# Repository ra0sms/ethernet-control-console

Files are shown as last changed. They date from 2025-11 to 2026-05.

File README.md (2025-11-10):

### Ethernet control console

The device allows you to control 8 outputs via an Ethernet connection. The main outputs control voltage and are also duplicated by open-collector outputs.

Input VDC: 5-45 V

Output current: 500 mA for all 8 outputs (also 500 mA for all open-collector outputs)

PCB dimension: 78*88 mm

[WI-FI version with the same functionality](https://github.com/ra0sms/ESP8266_antenna_switch)

More information - https://ra0sms.com/ethernet-control-console

#### Schematic

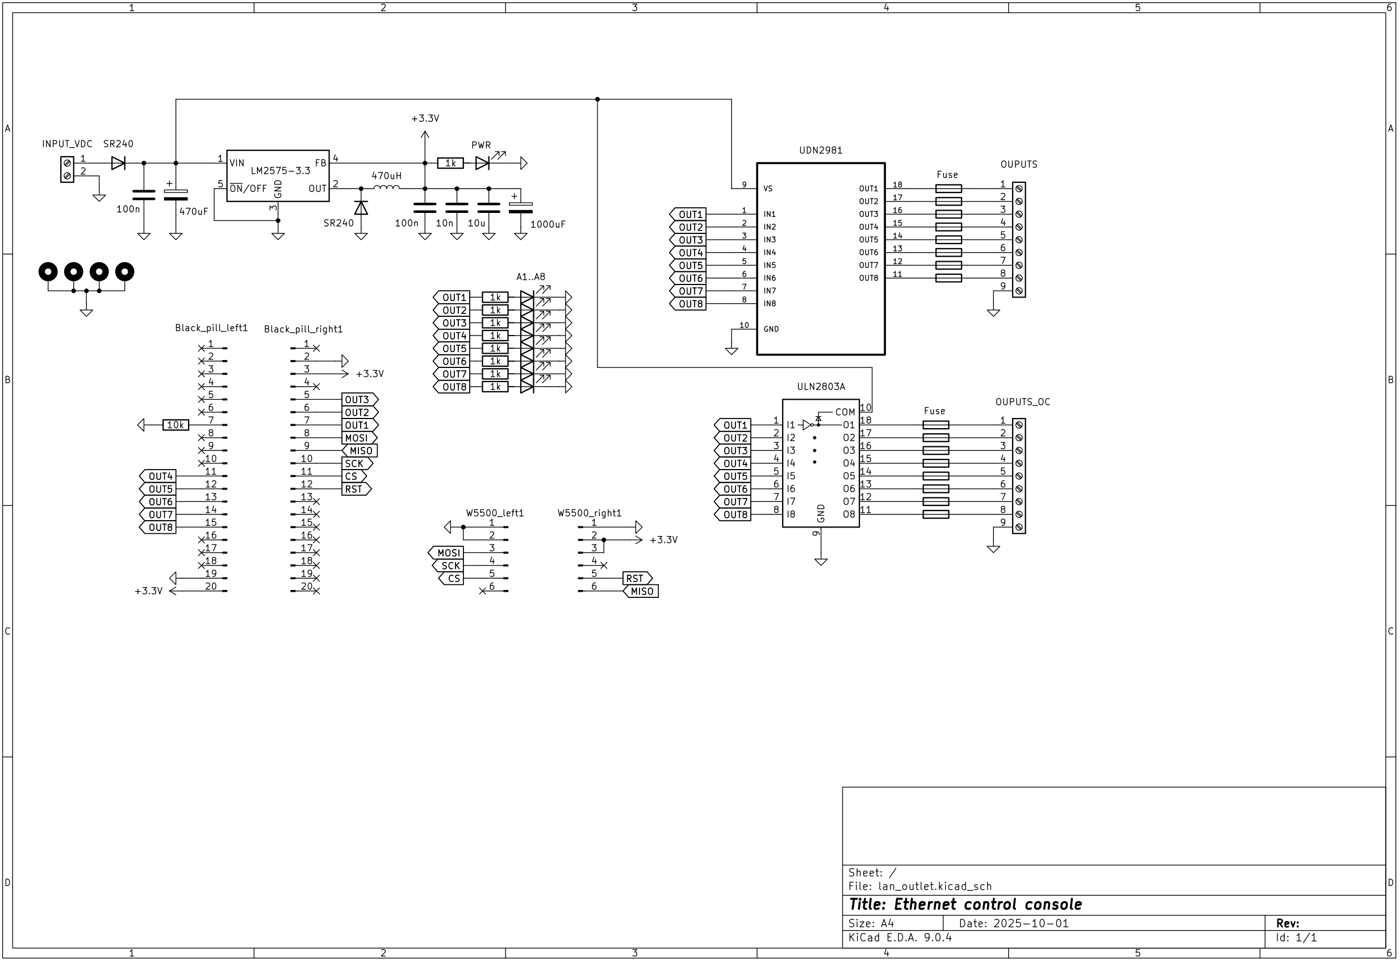
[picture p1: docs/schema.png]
schema


#### PCB

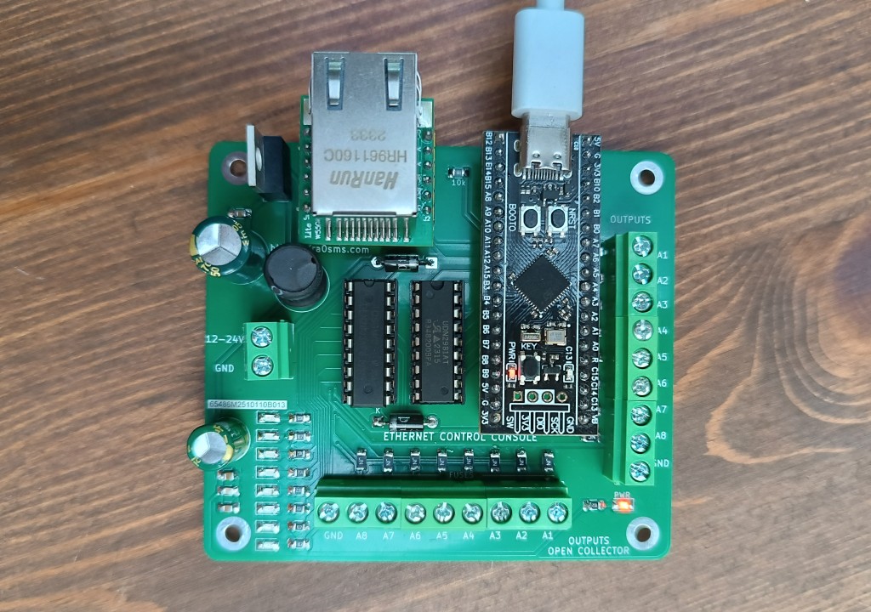
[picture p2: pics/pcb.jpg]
pcb


#### Boxed version

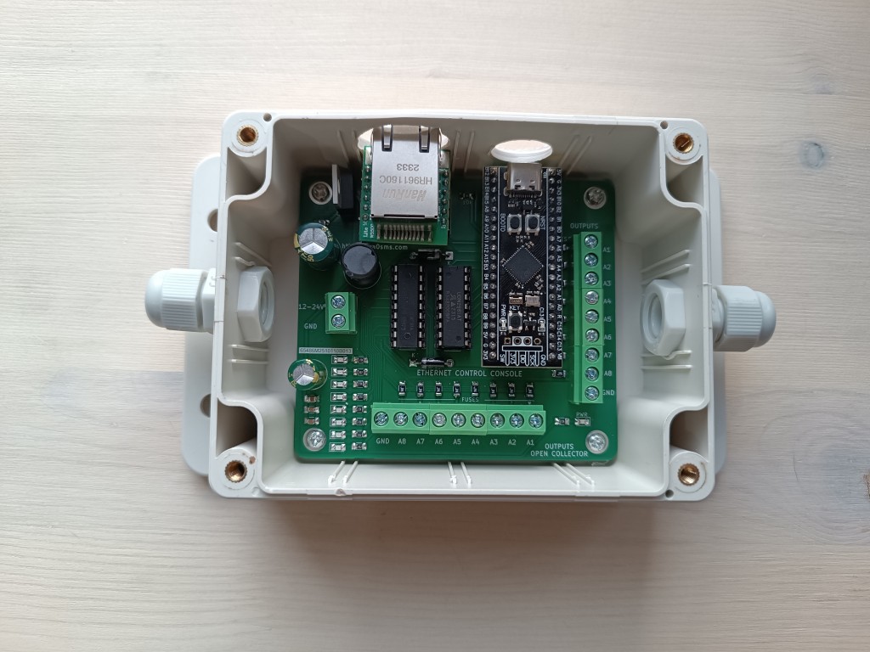
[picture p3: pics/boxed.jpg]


#### Web interface

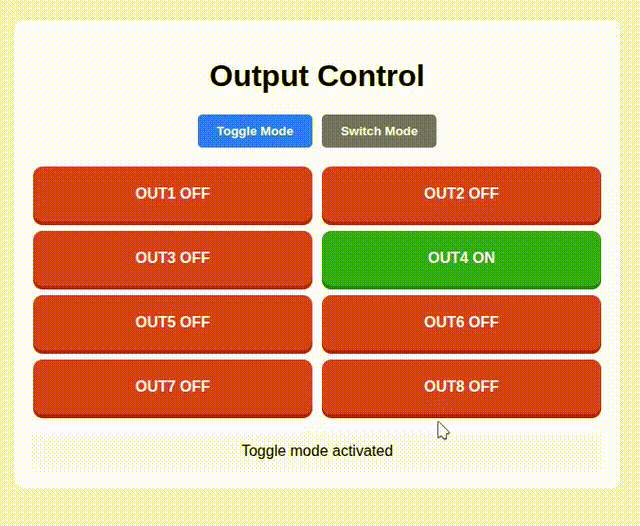
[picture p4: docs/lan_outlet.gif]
web


#### Configuration software

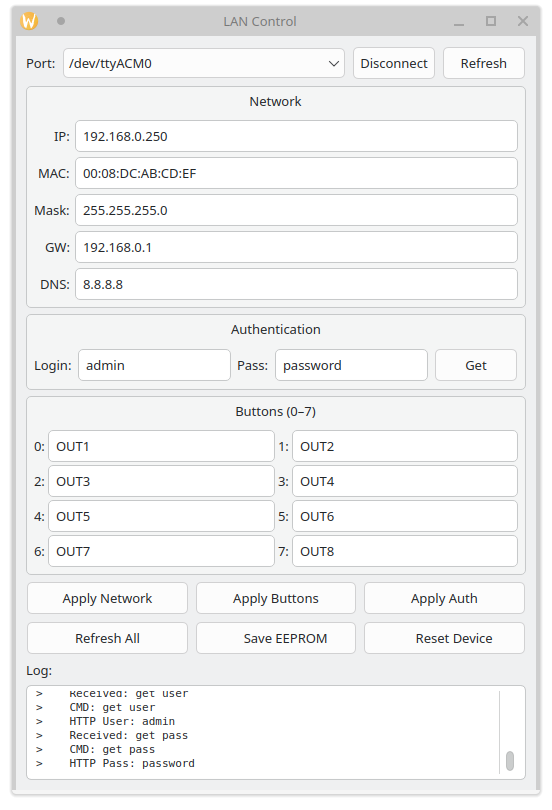
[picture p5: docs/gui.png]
gui


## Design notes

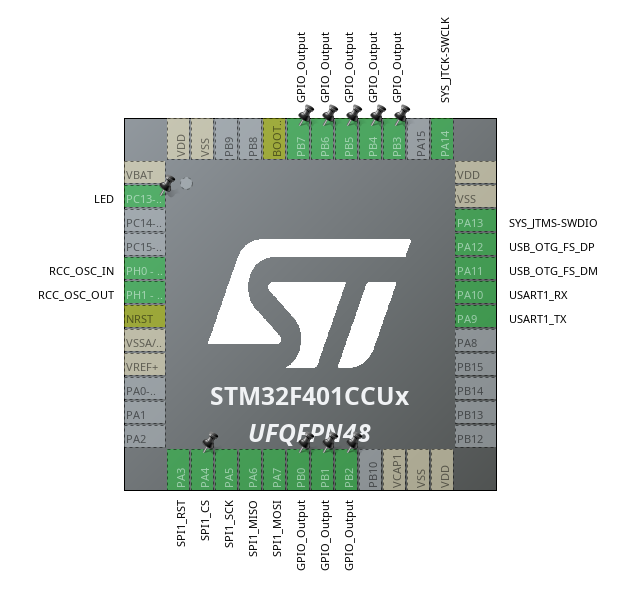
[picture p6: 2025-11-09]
docs/lan_outlet_pinout.png

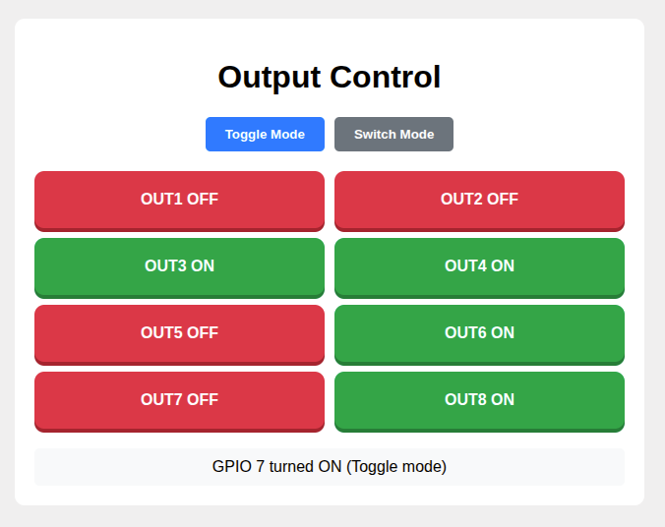
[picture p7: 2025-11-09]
docs/web.png

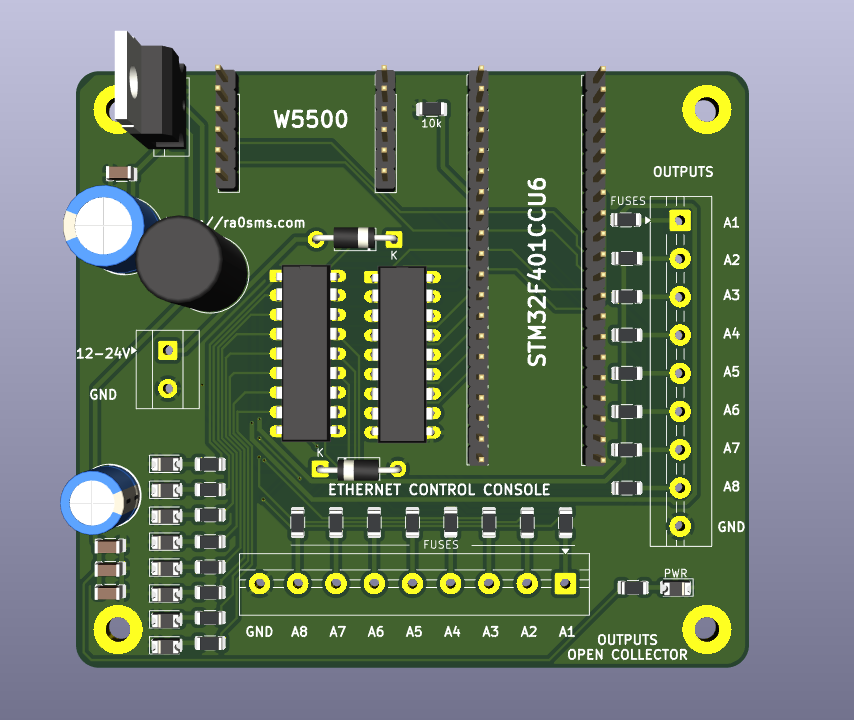
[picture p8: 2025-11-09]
docs/3d.png

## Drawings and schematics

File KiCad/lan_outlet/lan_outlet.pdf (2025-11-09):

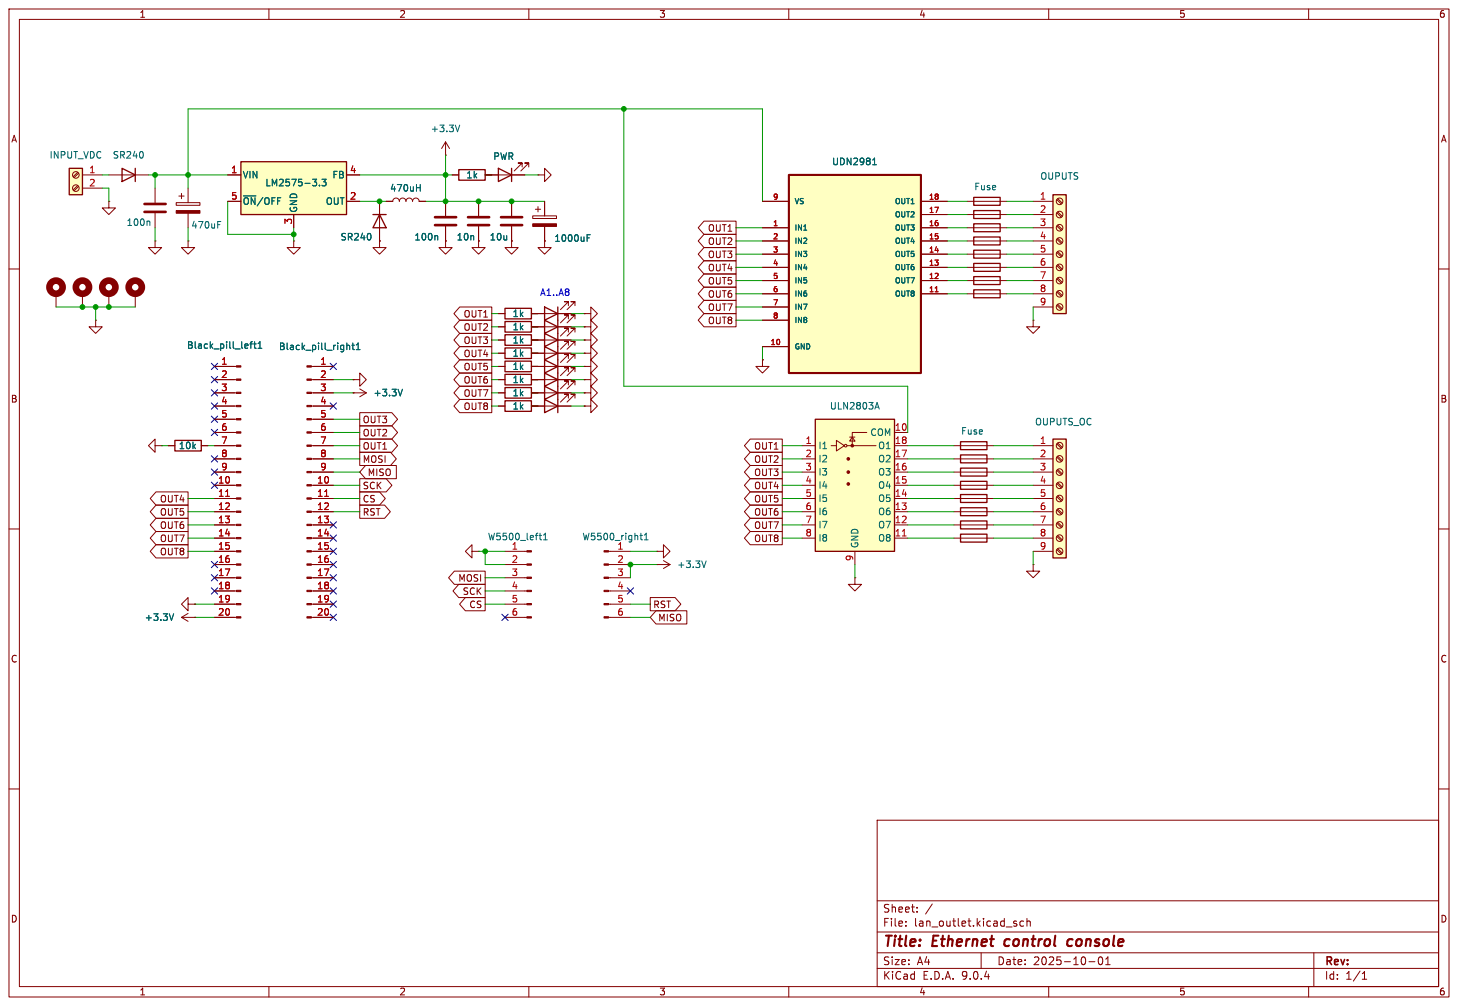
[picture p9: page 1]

File: lan_outlet.kicad_sch Sheet: /
Id: 1/1 Title: Ethernet control console

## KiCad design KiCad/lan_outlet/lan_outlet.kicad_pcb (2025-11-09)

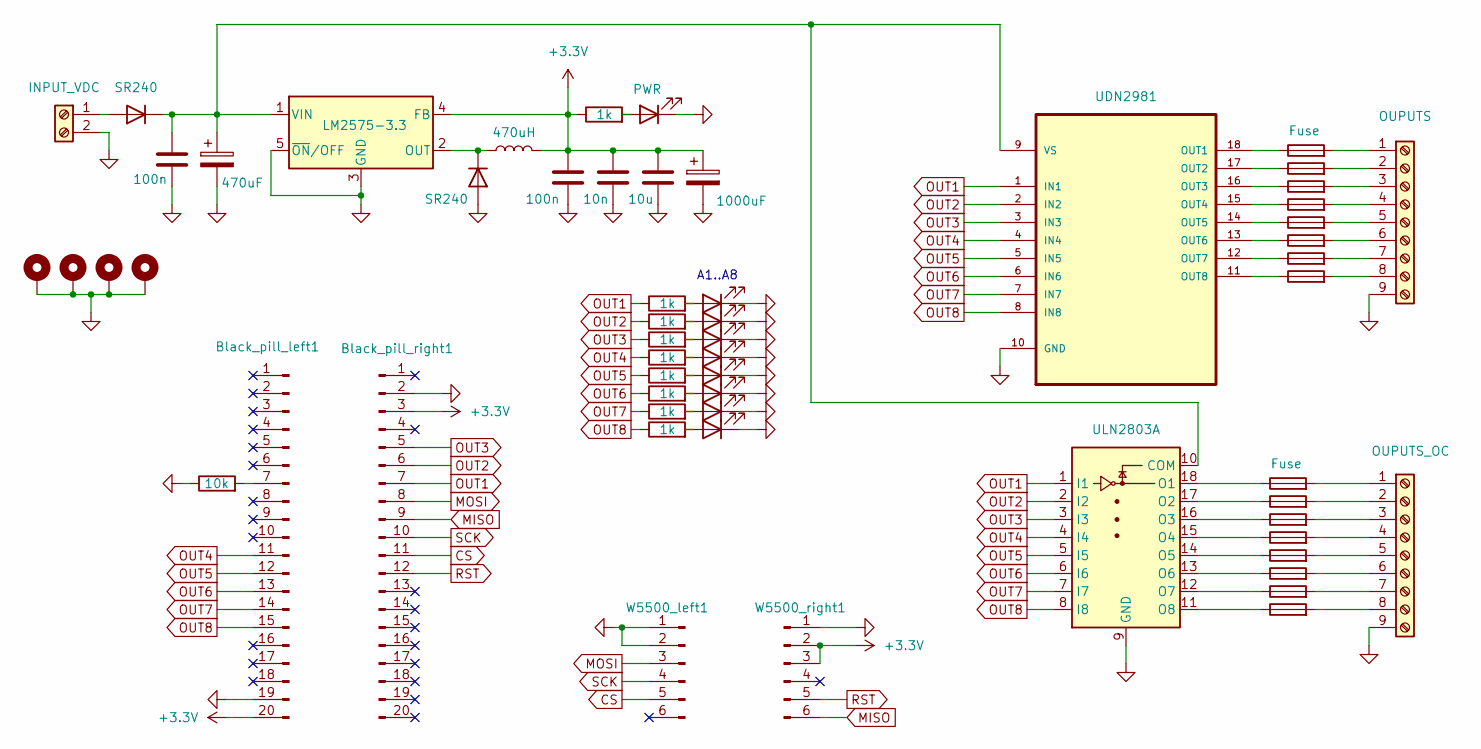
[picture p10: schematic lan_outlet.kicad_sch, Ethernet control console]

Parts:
Black_pill_left1: Conn_01x20_Pin; PinHeader_1x20_P2.54mm_Vertical
Black_pill_right1: Conn_01x20_Pin; PinHeader_1x20_P2.54mm_Vertical
C1, C3: 100n; C_1206_3216Metric
C2: 470uF; CP_Radial_D10.0mm_P5.00mm
C4: 10n; C_1206_3216Metric
C5: 10u; C_1206_3216Metric
C6: 1000uF; CP_Radial_D8.0mm_P3.80mm
D1, D2: SR240; D_DO-41_SOD81_P10.16mm_Horizontal
D3: PWR; D_1206_3216Metric
D4, D5, D6, D7, D8, D9, D10, D11: A1; D_1206_3216Metric
F1, F2, F3, F4, F5, F6, F7, F8, F9, F10, F11, F12, F13, F14, F15, F16: Fuse; R_1206_3216Metric
H1, H2, H3, H4: MountingHole_Pad; MountingHole_3.2mm_M3_Pad
J1: INPUT_VDC; TerminalBlock_MetzConnect_Type055_RT01502HDWU_1x02_P5.00mm_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
J2: OUPUTS; TerminalBlock_MaiXu_MX126-5.0-09P_1x09_P5.00mm
J3: OUPUTS_OC; TerminalBlock_MaiXu_MX126-5.0-09P_1x09_P5.00mm
L1: 470uH; L_Radial_D10.0mm_P5.00mm_Neosid_SD12_style3
R1: 10k; R_1206_3216Metric
R2, R3, R4, R5, R6, R7, R8, R9, R10: 1k; R_1206_3216Metric
U1: LM2575-3.3; TO-220-5_Vertical
U2: UDN2981; DIP-18_W7.62mm_LongPads; MPN UDN2981
U3: ULN2803A; DIP-18_W7.62mm_LongPads
W5500_left1, W5500_right1: Conn_01x06_Pin; PinHeader_1x06_P2.54mm_Vertical

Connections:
+3.3V: Black_pill_left1.20, Black_pill_right1.3, C3.1, C4.1, C5.1, C6.1, L1.2, R2.1, U1.4 (FB), W5500_right1.2, W5500_right1.3
CS: Black_pill_right1.11, W5500_left1.5
GND: Black_pill_left1.19, Black_pill_right1.2, C1.2, C2.2, C3.2, C4.2, C5.2, C6.2, D2.2 (A), D3.1 (K), D4.1 (K), D5.1 (K), D6.1 (K), D7.1 (K), D8.1 (K), D9.1 (K), D10.1 (K), D11.1 (K), H1.1, H2.1, H3.1, H4.1, J1.2, J2.9, J3.9, R1.1, U1.3 (GND), U1.5 (~ON/OFF), U2.10 (GND), U3.9 (GND), W5500_left1.1, W5500_left1.2, W5500_right1.1
MISO: Black_pill_right1.9, W5500_right1.6
MOSI: Black_pill_right1.8, W5500_left1.3
unnamed: Black_pill_left1.7, R1.2
unnamed: D1.2 (A), J1.1
unnamed: C1.1, C2.1, D1.1 (K), U1.1 (VIN), U2.9 (VS), U3.10 (COM)
unnamed: D2.1 (K), L1.1, U1.2 (OUT)
unnamed: D3.2 (A), R2.2
unnamed: D4.2 (A), R3.2
unnamed: D5.2 (A), R4.2
unnamed: D6.2 (A), R5.2
unnamed: D7.2 (A), R6.2
unnamed: D8.2 (A), R7.2
unnamed: D9.2 (A), R8.2
unnamed: D10.2 (A), R9.2
unnamed: D11.2 (A), R10.2
unnamed: F9.2, J2.1
unnamed: F10.2, J2.2
unnamed: F11.2, J2.3
unnamed: F12.2, J2.4
unnamed: F13.2, J2.5
unnamed: F14.2, J2.6
unnamed: F15.2, J2.7
unnamed: F16.2, J2.8
unnamed: F1.2, J3.1
unnamed: F2.2, J3.2
unnamed: F3.2, J3.3
unnamed: F4.2, J3.4
unnamed: F5.2, J3.5
unnamed: F6.2, J3.6
unnamed: F7.2, J3.7
unnamed: F8.2, J3.8
unnamed: F9.1, U2.18 (OUT1)
unnamed: F10.1, U2.17 (OUT2)
unnamed: F11.1, U2.16 (OUT3)
unnamed: F12.1, U2.15 (OUT4)
unnamed: F13.1, U2.14 (OUT5)
unnamed: F14.1, U2.13 (OUT6)
unnamed: F15.1, U2.12 (OUT7)
unnamed: F16.1, U2.11 (OUT8)
unnamed: F1.1, U3.18 (O1)
unnamed: F2.1, U3.17 (O2)
unnamed: F3.1, U3.16 (O3)
unnamed: F4.1, U3.15 (O4)
unnamed: F5.1, U3.14 (O5)
unnamed: F6.1, U3.13 (O6)
unnamed: F7.1, U3.12 (O7)
unnamed: F8.1, U3.11 (O8)
OUT1: Black_pill_right1.7, R3.1, U2.1 (IN1), U3.1 (I1)
OUT2: Black_pill_right1.6, R4.1, U2.2 (IN2), U3.2 (I2)
OUT3: Black_pill_right1.5, R5.1, U2.3 (IN3), U3.3 (I3)
OUT4: Black_pill_left1.11, R6.1, U2.4 (IN4), U3.4 (I4)
OUT5: Black_pill_left1.12, R7.1, U2.5 (IN5), U3.5 (I5)
OUT6: Black_pill_left1.13, R8.1, U2.6 (IN6), U3.6 (I6)
OUT7: Black_pill_left1.14, R9.1, U2.7 (IN7), U3.7 (I7)
OUT8: Black_pill_left1.15, R10.1, U2.8 (IN8), U3.8 (I8)
RST: Black_pill_right1.12, W5500_right1.5
SCK: Black_pill_right1.10, W5500_left1.4

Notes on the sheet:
A1..A8

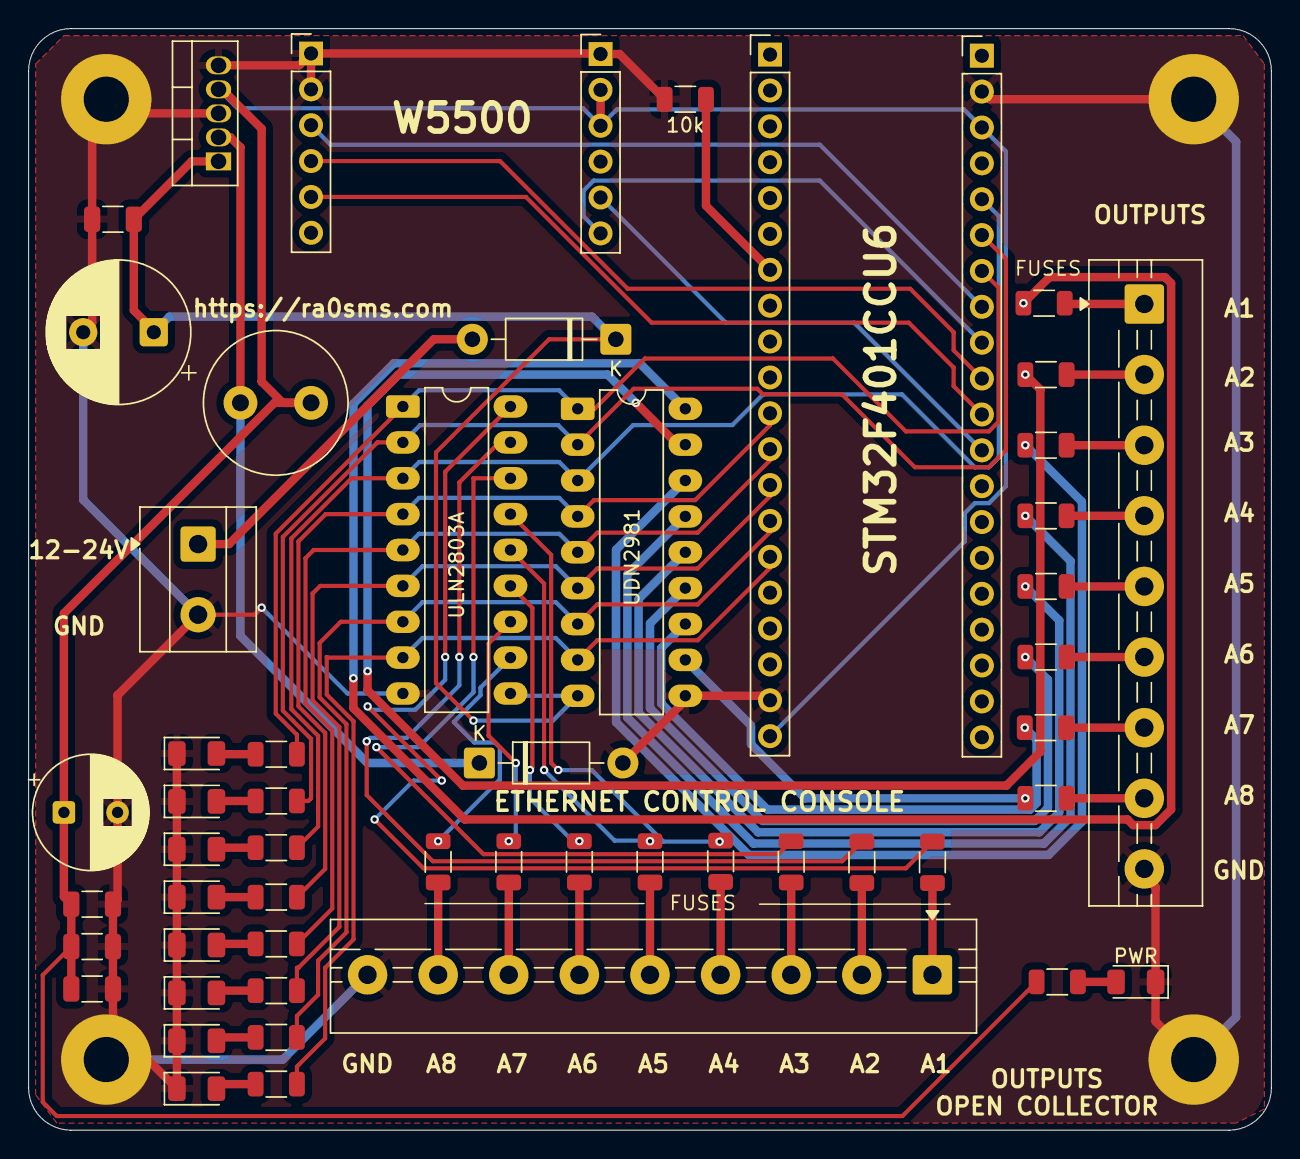
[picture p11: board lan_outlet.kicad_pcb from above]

Board: 2 copper layers, 88.0 x 78.0 mm, 58 parts (0 on the bottom side), 60 nets.

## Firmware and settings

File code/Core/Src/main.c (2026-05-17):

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
/* Includes ------------------------------------------------------------------*/
#include "main.h"
#include "usb_device.h"
#include "usbd_cdc_if.h"

/* USER CODE BEGIN Includes */
#include "socket.h"
#include <stdio.h>
#include <string.h>
#include <ctype.h>
#include "stm32f4xx_hal_flash.h"

#define AUTH_ON
#define HTTP_SOCKET     0
#define DATA_BUF_SIZE   16384
#define MAX_SOCK_NUM 8
#define HTTP_PORT 80
#define EEPROM_START_ADDRESS 0x08030000
#define EEPROM_MAGIC_NUMBER 0xABCD1235

uint8_t gDATABUF[DATA_BUF_SIZE];
uint8_t stat;
uint32_t socket_active_since = 0;
char g_http_user[32] = "admin";
char g_http_pass[32] = "password";
char g_http_base64[64] = "";

extern volatile uint8_t usb_rx_buffer[USB_RX_BUFFER_SIZE];
extern volatile uint16_t usb_rx_index;
extern volatile uint8_t usb_rx_ready;
extern volatile uint8_t usb_rx_error;


uint8_t gpio_states[8] = {0};
char last_status_message[128] = {0};
uint8_t operation_mode = 0;
uint8_t dual_mode_group1 = 0;
uint8_t dual_mode_group2 = 0;
char mode_names[3][16] = {"Toggle Mode", "Switch Mode", "Dual Mode"};

int ParseIPAddress(const char* ip_str, uint8_t* ip_array);
int ParseMACAddress(const char* mac_str, uint8_t* mac_array);
void ApplyNetworkSettings(void);
void ShowNetworkInfo(void);
void ProcessSetCommand(char* args);
void ProcessGetCommand(char* args);
void ProcessSetButtonCommand(char* args);
void LoadButtonNamesFromEEPROM(void);
void ShowButtonNames(void);
void TrimWhitespace(char* str);

#pragma pack(push, 1)
typedef struct {
    uint32_t magic;
    wiz_NetInfo netinfo;
    char button_names[8][16];
    char http_user[32];
    char http_pass[32];
    uint32_t crc;
} EEPROM_Data;
#pragma pack(pop)

char button_names[8][16] = {
    "OUT1", "OUT2", "OUT3", "OUT4",
    "OUT5", "OUT6", "OUT7", "OUT8"
};


const char *http_headers =
    "HTTP/1.1 200 OK\r\n"
    "Content-Type: text/html\r\n"
    "Connection: close\r\n"
    "\r\n";


const char *main_page =
    "<!DOCTYPE html>"
    "<html><head><title>LAN Control Console</title>"
    "<meta charset='UTF-8'>"
    "<meta name='viewport' content='width=device-width, initial-scale=1.0'>"
    "<style>"
    "body{font-family:Arial;background:#f0f0f0;text-align:center;padding:20px;}"
    ".container{background:white;border-radius:10px;padding:20px;margin:0 auto;max-width:600px;}"
    ".mode-selector{margin:15px 0;}"
    ".mode-btn{padding:10px 20px;margin:0 5px;border:none;border-radius:5px;cursor:pointer;font-weight:bold;}"
    ".mode-active{background:#007bff;color:white;}"
    ".mode-inactive{background:#6c757d;color:white;}"
    ".btn-grid{display:grid;grid-template-columns:repeat(2,1fr);gap:10px;margin:20px 0;}"
    ".btn{display:block;padding:20px;border-radius:10px;text-decoration:none;font-size:16px;font-weight:bold;transition:all 0.3s;}"
    ".btn-on{background:#28a745;color:white;box-shadow:0 4px #1e7e34;}"
    ".btn-off{background:#dc3545;color:white;box-shadow:0 4px #a71e2a;}"
    ".btn:hover{opacity:0.9;transform:translateY(-2px);}"
    ".status{margin-top:20px;padding:10px;border-radius:5px;background:#f8f9fa;}"
    "</style>"
    "</head>"
    "<body>"
    "<div class='container'>"
    "<h1>Output Control</h1>";


/* USER CODE END Includes */

SPI_HandleTypeDef hspi1;

UART_HandleTypeDef huart1;

/* USER CODE BEGIN PV */
wiz_NetInfo gWIZNETINFO = { .mac = {0x00, 0x08, 0xdc, 0xab, 0xcd, 0xef},
                            .ip = {192, 168, 0, 250},
                            .sn = {255, 255, 255, 0},
                            .gw = {192, 168, 0, 1},
                            .dns = {0, 0, 0, 0},
                            .dhcp = NETINFO_STATIC };



static const char base64_chars[] = "ABCDEFGHIJKLMNOPQRSTUVWXYZabcdefghijklmnopqrstuvwxyz0123456789+/";

void base64_encode(const unsigned char* data, size_t input_length, char* output) {
    size_t i = 0, j = 0;
    uint32_t triple;

    while (i + 3 <= input_length) {
        triple = (data[i] << 16) + (data[i+1] << 8) + data[i+2];
        output[j++] = base64_chars[(triple >> 18) & 0x3F];
        output[j++] = base64_chars[(triple >> 12) & 0x3F];
        output[j++] = base64_chars[(triple >>  6) & 0x3F];
        output[j++] = base64_chars[(triple      ) & 0x3F];
        i += 3;
    }

    if (i + 2 == input_length) {
        triple = (data[i] << 16) + (data[i+1] << 8);
        output[j++] = base64_chars[(triple >> 18) & 0x3F];
        output[j++] = base64_chars[(triple >> 12) & 0x3F];
        output[j++] = base64_chars[(triple >>  6) & 0x3F];
        output[j++] = '=';
    } else if (i + 1 == input_length) {
        triple = (data[i] << 16);
        output[j++] = base64_chars[(triple >> 18) & 0x3F];
        output[j++] = base64_chars[(triple >> 12) & 0x3F];
        output[j++] = '=';
        output[j++] = '=';
    }
    output[j] = '\0';
}

void UpdateHTTPBase64(void) {
    char userpass[64];
    int len = snprintf(userpass, sizeof(userpass), "%s:%s", g_http_user, g_http_pass);
    if (len > 0 && len < (int)sizeof(userpass)) {
        base64_encode((const unsigned char*)userpass, len, g_http_base64);
    } else {
        strcpy(g_http_base64, "");
    }
}


int check_authentication(uint8_t* http_request) {
    char* auth_header = strstr((char*)http_request, "Authorization: Basic ");
    if (auth_header == NULL) {
        return 0;
    }
    auth_header += strlen("Authorization: Basic ");
    char* end_of_auth = strchr(auth_header, '\r');
    if (end_of_auth == NULL) {
        return 0;
    }
    int encoded_len = end_of_auth - auth_header;
    char encoded[64] = {0};
    if (encoded_len >= 63) return 0; // safety
    strncpy(encoded, auth_header, encoded_len);
    encoded[encoded_len] = '\0';

    return (strcmp(encoded, g_http_base64) == 0);
}

void send_auth_required(uint8_t socket) {
    const char* auth_page =
        "HTTP/1.1 401 Unauthorized\r\n"
        "WWW-Authenticate: Basic realm=\"LAN Control Console\"\r\n"
        "Content-Type: text/html\r\n"
  //      "Connection: close\r\n"
        "Content-Length: 0\r\n\r\n";

    send(socket, (uint8_t*)auth_page, strlen(auth_page));
}


int _write(int file, char *ptr, int len)
{
    CDC_Transmit_FS((uint8_t*)ptr, len);
    return len;
}


void W5500_Select(void)
{
    HAL_GPIO_WritePin(SPI1_CS_GPIO_Port, SPI1_CS_Pin, GPIO_PIN_RESET);
}

void W5500_Unselect(void)
{
    HAL_GPIO_WritePin(SPI1_CS_GPIO_Port, SPI1_CS_Pin, GPIO_PIN_SET);
}

void W5500_ReadBuff(uint8_t* buff, uint16_t len)
{
    HAL_SPI_Receive(&hspi1, buff, len, 100);
}

void W5500_WriteBuff(uint8_t* buff, uint16_t len)
{
    HAL_SPI_Transmit(&hspi1, buff, len, 100);
}

uint8_t W5500_ReadByte(void)
{
    uint8_t byte;
    W5500_ReadBuff(&byte, sizeof(byte));
    return byte;
}

void W5500_WriteByte(uint8_t byte)
{
    W5500_WriteBuff(&byte, sizeof(byte));
}




uint32_t CalculateXORChecksum(const uint8_t* data, size_t length)
{
    uint32_t checksum = 0;
    for(size_t i = 0; i < length; i++) {
        checksum ^= data[i];
    }
    return checksum;
}


void WriteSettingsToEEPROM(void)
{
    EEPROM_Data eeprom_data = {0};
    eeprom_data.magic = EEPROM_MAGIC_NUMBER;
    memcpy(&eeprom_data.netinfo, &gWIZNETINFO, sizeof(wiz_NetInfo));
    for(int i = 0; i < 8; i++) {
        strncpy(eeprom_data.button_names[i], button_names[i], 15);
        eeprom_data.button_names[i][15] = '\0';
    }
    strncpy(eeprom_data.http_user, g_http_user, 31);
    eeprom_data.http_user[31] = '\0';
    strncpy(eeprom_data.http_pass, g_http_pass, 31);
    eeprom_data.http_pass[31] = '\0';
    size_t checksum_size = sizeof(EEPROM_Data) - sizeof(uint32_t);
    eeprom_data.crc = CalculateXORChecksum((uint8_t*)&eeprom_data, checksum_size);

    printf("XOR Checksum: 0x%08lX\r\n", (unsigned long)eeprom_data.crc);

    HAL_FLASH_Unlock();
    __HAL_FLASH_CLEAR_FLAG(FLASH_FLAG_EOP | FLASH_FLAG_OPERR | FLASH_FLAG_WRPERR |
                          FLASH_FLAG_PGAERR | FLASH_FLAG_PGSERR);

    FLASH_EraseInitTypeDef erase_init = {0};
    erase_init.TypeErase = FLASH_TYPEERASE_SECTORS;
    erase_init.Sector = FLASH_SECTOR_5;
    erase_init.NbSectors = 1;
    erase_init.VoltageRange = FLASH_VOLTAGE_RANGE_3;

    uint32_t sector_error = 0;
    if (HAL_FLASHEx_Erase(&erase_init, &sector_error) != HAL_OK) {
        printf("Flash erase failed\r\n");
        HAL_FLASH_Lock();
        return;
    }
    uint32_t* data_ptr = (uint32_t*)&eeprom_data;
    uint32_t word_count = (sizeof(EEPROM_Data) + 3) / 4;
    uint32_t address = EEPROM_START_ADDRESS;
    for (uint32_t i = 0; i < word_count; i++) {
        if (HAL_FLASH_Program(FLASH_TYPEPROGRAM_WORD, address + i * 4, data_ptr[i]) != HAL_OK) {
            printf("Flash write failed at word %lu\r\n", i);
            break;
        }
    }
    HAL_FLASH_Lock();
    printf("Settings saved to EEPROM\r\n");
}


uint8_t ReadSettingsFromEEPROM(void)
{
    EEPROM_Data* eeprom_data = (EEPROM_Data*)EEPROM_START_ADDRESS;

    printf("Magic in EEPROM: 0x%08X, expected: 0x%08X\r\n",
           (unsigned int)eeprom_data->magic, (unsigned int)EEPROM_MAGIC_NUMBER);

    if(eeprom_data->magic != EEPROM_MAGIC_NUMBER) {
        printf("No valid settings in EEPROM\r\n");
        return 0;
    }

    size_t checksum_size = sizeof(EEPROM_Data) - sizeof(uint32_t);
    uint32_t calculated_checksum = CalculateXORChecksum((uint8_t*)eeprom_data, checksum_size);
    printf("Stored XOR: 0x%08X, Calculated XOR: 0x%08X\r\n",
           (unsigned int)eeprom_data->crc, (unsigned int)calculated_checksum);

    if(eeprom_data->crc != calculated_checksum) {
        printf("EEPROM data corrupted (XOR checksum error)\r\n");
        return 0;
    }

    memcpy(&gWIZNETINFO, &eeprom_data->netinfo, sizeof(wiz_NetInfo));

    for(int i = 0; i < 8; i++) {
        strncpy(button_names[i], eeprom_data->button_names[i], 15);
        button_names[i][15] = '\0';
        printf("Button %d: '%s'\r\n", i, button_names[i]);
        HAL_Delay(1);
    }
    strncpy(g_http_user, eeprom_data->http_user, 31);
    g_http_user[31] = '\0';
    strncpy(g_http_pass, eeprom_data->http_pass, 31);
    g_http_pass[31] = '\0';
    UpdateHTTPBase64();
    printf("Settings loaded from EEPROM\r\n");
    return 1;
}



void LoadDefaultSettings(void)
{
    uint8_t default_mac[] = {0x00, 0x08, 0xDC, 0xAB, 0xCD, 0xEF};
    uint8_t default_ip[] = {192, 168, 0, 250};
    uint8_t default_sn[] = {255, 255, 255, 0};
    uint8_t default_gw[] = {192, 168, 0, 1};
    uint8_t default_dns[] = {8, 8, 8, 8};

    memcpy(gWIZNETINFO.mac, default_mac, 6);
    memcpy(gWIZNETINFO.ip, default_ip, 4);
    memcpy(gWIZNETINFO.sn, default_sn, 4);
    memcpy(gWIZNETINFO.gw, default_gw, 4);
    memcpy(gWIZNETINFO.dns, default_dns, 4);
    gWIZNETINFO.dhcp = NETINFO_STATIC;
    char default_names[8][16] = {
        "OUT1", "OUT2", "OUT3", "OUT4",
        "OUT5", "OUT6", "OUT7", "OUT8"
    };

    for(int i = 0; i < 8; i++) {
        strncpy(button_names[i], default_names[i], 15);
        button_names[i][15] = '\0';
    }
    strncpy(g_http_user, "admin", 31);
    g_http_user[31] = '\0';
    strncpy(g_http_pass, "password", 31);
    g_http_pass[31] = '\0';
    UpdateHTTPBase64();

    printf("Loaded default settings\r\n");
}
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
int main(void)
{
  /* MCU Configuration--------------------------------------------------------*/

  HAL_Init();
  SystemClock_Config();
  MX_GPIO_Init();
  MX_SPI1_Init();
  MX_TIM11_Init();
  MX_USB_DEVICE_Init();

  /* USER CODE BEGIN 2 */
  LL_TIM_EnableCounter(TIM11);
  LL_TIM_EnableIT_UPDATE(TIM11);

  HAL_Delay(2000);

  // Загрузка настроек из EEPROM или дефолтных
  if (!ReadSettingsFromEEPROM()) {
      LoadDefaultSettings();
      printf("Using default settings\r\n");
  } else {
      printf("Settings loaded from EEPROM\r\n");
  }
  ApplyNetworkSettings();
  UpdateHTTPBase64();

  // Инициализация режимов работы
  operation_mode = 0;              // 0=Toggle(global), 1=Switch(global), 2=Dual
  dual_mode_group1 = 0;            // 0=toggle, 1=switch для GPIO 0-3 (выходы 1-4)
  dual_mode_group2 = 0;            // 0=toggle, 1=switch для GPIO 4-7 (выходы 5-8)

  printf("System initialized\r\n");

  // Сброс и инициализация W5500
  HAL_GPIO_WritePin(SPI1_RST_GPIO_Port, SPI1_RST_Pin, GPIO_PIN_RESET);
  HAL_Delay(10);
  HAL_GPIO_WritePin(SPI1_RST_GPIO_Port, SPI1_RST_Pin, GPIO_PIN_SET);
  HAL_Delay(2000);

  reg_wizchip_cs_cbfunc(W5500_Select, W5500_Unselect);
  reg_wizchip_spi_cbfunc(W5500_ReadByte, W5500_WriteByte);
  reg_wizchip_spiburst_cbfunc(W5500_ReadBuff, W5500_WriteBuff);

  uint8_t rx_tx_buff_sizes[] = { 8, 1, 1, 1, 1, 1, 1, 1 };
  wizchip_init(rx_tx_buff_sizes, rx_tx_buff_sizes);
  wizchip_setnetinfo(&gWIZNETINFO);

  printf("W5500 initialized, IP: %d.%d.%d.%d\r\n", gWIZNETINFO.ip[0],
          gWIZNETINFO.ip[1], gWIZNETINFO.ip[2], gWIZNETINFO.ip[3]);

  if (socket(HTTP_SOCKET, Sn_MR_TCP, 80, 0) != HTTP_SOCKET) {
      printf("Socket creation failed!\r\n");
      while (1) { HAL_Delay(1000); }
  }

  if (listen(HTTP_SOCKET) != SOCK_OK) {
      printf("Listen failed!\r\n");
      while (1) { HAL_Delay(1000); }
  }

  printf("HTTP Server listening on port 80...\r\n");

  /* USER CODE END 2 */

  /* Infinite loop */
  /* USER CODE BEGIN WHILE */
  while (1)
  {
    ProcessUSBData();
    CheckW5500();
    EnsureSocketClosedIfNeeded();

    uint8_t status = getSn_SR(HTTP_SOCKET);
    uint32_t now = HAL_GetTick();

    // Контроль "зависшего" сокета
    if ((status == SOCK_ESTABLISHED || status == SOCK_CLOSE_WAIT) && socket_active_since != 0) {
        if (now - socket_active_since > 10000) {
            printf("Socket stuck >10s, force closing socket %d\r\n", HTTP_SOCKET);
            close(HTTP_SOCKET);
            socket_active_since = 0;
        }
    }

    switch (status) {
    case SOCK_ESTABLISHED: {
        if (socket_active_since == 0) {
            socket_active_since = now;
        }

        uint8_t http_request[1024] = { 0 };
        uint16_t total_len = 0;
        uint32_t recv_start = HAL_GetTick();

        // Приём HTTP-запроса
        while (total_len < sizeof(http_request) - 1) {
            int16_t len = recv(HTTP_SOCKET, http_request + total_len,
                    sizeof(http_request) - total_len - 1);

            if (len > 0) {
                total_len += len;
                recv_start = HAL_GetTick();
                if (total_len >= 4 && memcmp(http_request + total_len - 4, "\r\n\r\n", 4) == 0) {
                    break;
                }
            } else if (len == 0) {
                if (HAL_GetTick() - recv_start > 3000) {
                    printf("Recv timeout\r\n");
                    break;
                }
                HAL_Delay(1);
            } else {
                printf("Recv error: %d\r\n", len);
                break;
            }
        }

        if (total_len > 0) {
            http_request[total_len] = '\0';

            // === ПРОВЕРКА АУТЕНТИФИКАЦИИ ===
#ifdef AUTH_ON
            if (strstr((char*) http_request, "GET /favicon.ico") == NULL) {
                if (!check_authentication(http_request)) {
                    send_auth_required(HTTP_SOCKET);
                    uint32_t start = HAL_GetTick();
                    while (getSn_TX_RD(HTTP_SOCKET) != getSn_TX_WR(HTTP_SOCKET)) {
                        if (HAL_GetTick() - start > 500 || getSn_SR(HTTP_SOCKET) != SOCK_ESTABLISHED) {
                            break;
                        }
                        HAL_Delay(1);
                    }
                    goto skip_page_serve_and_close;
                }
            }
#endif

            // === ОБРАБОТКА СМЕНЫ РЕЖИМОВ ===
            if (strstr((char*) http_request, "GET /mode/toggle")) {
                operation_mode = 0;
                snprintf(last_status_message, sizeof(last_status_message), "Toggle Mode (global)");
                printf("Global Toggle mode\r\n");
            }
            else if (strstr((char*) http_request, "GET /mode/switch")) {
                operation_mode = 1;
                snprintf(last_status_message, sizeof(last_status_message), "Switch Mode (global)");
                printf("Global Switch mode\r\n");
            }
            else if (strstr((char*) http_request, "GET /mode/dual")) {
                operation_mode = 2;
                snprintf(last_status_message, sizeof(last_status_message), "Dual Mode active");
                printf("Dual mode activated\r\n");
            }
            // Настройка группы 1 внутри Dual Mode
            else if (strstr((char*) http_request, "GET /dual/g1/toggle")) {
                dual_mode_group1 = 0;
                snprintf(last_status_message, sizeof(last_status_message), "Group 1: Toggle");
                printf("Dual: Group 1 -> Toggle\r\n");
            }
            else if (strstr((char*) http_request, "GET /dual/g1/switch")) {
                dual_mode_group1 = 1;
                snprintf(last_status_message, sizeof(last_status_message), "Group 1: Switch");
                printf("Dual: Group 1 -> Switch\r\n");
            }
            // Настройка группы 2 внутри Dual Mode
            else if (strstr((char*) http_request, "GET /dual/g2/toggle")) {
                dual_mode_group2 = 0;
                snprintf(last_status_message, sizeof(last_status_message), "Group 2: Toggle");
                printf("Dual: Group 2 -> Toggle\r\n");
            }
            else if (strstr((char*) http_request, "GET /dual/g2/switch")) {
                dual_mode_group2 = 1;
                snprintf(last_status_message, sizeof(last_status_message), "Group 2: Switch");
                printf("Dual: Group 2 -> Switch\r\n");
            }

            // === ОБРАБОТКА УПРАВЛЕНИЯ ВЫХОДАМИ (ИСПРАВЛЕНО) ===
            for (int i = 0; i < 8; i++) {
                char on_pattern[20], off_pattern[20];
                snprintf(on_pattern, sizeof(on_pattern), "GET /gpio%d/on", i);
                snprintf(off_pattern, sizeof(off_pattern), "GET /gpio%d/off", i);

                // Определяем: нужно ли применять логику Switch для данного пина,
                // и в каком диапазоне выключать остальные
                uint8_t use_switch_logic = 0;
                int range_start = 0, range_end = 8;

                if (operation_mode == 1) {
                    // Глобальный Switch: выключаются ВСЕ остальные выходы (0-7)
                    use_switch_logic = 1;
                    range_start = 0;
                    range_end = 8;
                } else if (operation_mode == 2) {
                    // Dual Mode: выключаются только выходы в текущей группе
                    if (i < 4) {
                        use_switch_logic = (dual_mode_group1 == 1) ? 1 : 0;
                        range_start = 0;
                        range_end = 4;
                    } else {
                        use_switch_logic = (dual_mode_group2 == 1) ? 1 : 0;
                        range_start = 4;
                        range_end = 8;
                    }
                }
                // Если operation_mode == 0 (Global Toggle) -> use_switch_logic = 0
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

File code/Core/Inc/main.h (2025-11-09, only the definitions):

#define LED_Pin GPIO_PIN_13
#define LED_GPIO_Port GPIOC
#define SPI1_RST_Pin GPIO_PIN_3
#define SPI1_RST_GPIO_Port GPIOA
#define SPI1_CS_Pin GPIO_PIN_4
#define SPI1_CS_GPIO_Port GPIOA

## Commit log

2025-11-12 fix some issues with http requests
    [main.c]
2026-10-19 Fix hang without W5500, restore saved modes, tidy repo
    - Skip network code in main loop when W5500 is absent: the WIZnet
    socket library spins forever in close()/socket(), which blocked
    USB command processing (settings could not be saved on a bare
    Black Pill). W5500 is re-detected and initialized on the fly.
    - Pull-down on SPI1 MISO so a missing W5500 reads as 0x00.
    - Don't overwrite operation_mode / dual mode groups after loading
    them from EEPROM.
    - Limit code FLASH to 128K so it can't overlap the settings sector 5.
    - Add firmware/ with the current build, drop old hex files.
    - Stop tracking code/Debug build output (.gitignore).
    - Rewrite README: modes, flashing, defaults, USB command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
2026-10-19 Drive outputs low at the very start of main()
    PB0-PB7 stay floating inputs after reset until MX_GPIO_Init(), which
    runs only after the HSE/PLL clock setup. Drive them low first thing
    in main() to shorten the window where driver inputs float.
2026-10-19 Fix HTTP hang: non-blocking socket, watchdog, CSS/BOR handling
    - Open the HTTP socket with SF_IO_NONBLOCK. In blocking mode recv()
    spins forever while a client keeps the connection open without
    sending data (browser preconnect, sleeping phone), freezing the
    whole device. The request now has an overall 3 s limit.
    - Start IWDG (~4 s), refreshed in the main loop and bounded waits.
    - NMI: remove the endless loop; HSE failure (CSS) now resets the MCU.
    Error_Handler resets instead of hanging.
    - Enable BOR level 3 (2.7 V) via option bytes on first boot.
    - Report the last reset cause at boot and in the `network` command.
2026-10-19 Remove BOR option byte programming
    Writing BOR level 3 (2.7 V) from firmware can lock a board in reset
    permanently if its supply is slightly low: the MCU never starts and
    SWD can't connect. Firmware no longer touches option bytes.

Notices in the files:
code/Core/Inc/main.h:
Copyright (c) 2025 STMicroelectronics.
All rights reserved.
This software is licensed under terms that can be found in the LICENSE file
